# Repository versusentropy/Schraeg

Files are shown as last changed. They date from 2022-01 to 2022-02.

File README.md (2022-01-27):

# Schräg

Schräg is an 8HP multimode filter module for the eurorack format, based off the [Bastl Cinnamon](https://bastl-instruments.com/eurorack/modules/cinnamon).



## Smaller Warning and Disclaimer

As of 2021-03-01, at least one person has reported successfully building the current board revision. However, another builder reported a minor issue with the attenuverter circuits which prevents full-range voltage control over resonance (and limits voltage control over FM). This should be fixable only with component substitutions, we’re working on a fix. More information and updates [in the corresponding lines thread](https://llllllll.co/t/diy-module-release-schrag-bastl-cinnamon-rework/40590).

See the Changelog below for more updates and version-specific fixes.

## Quick links

* [Schematic](Schraeg/Schraeg.pdf)
* [Gerbers](Schraeg/output)
* [BOM](Schraeg/Schraeg%20BOM.csv)
* [Schräg on ModularGrid](https://www.modulargrid.net/e/other-unknown-schraeg)

## Features

Schräg is effectively a repackaged Bastl Cinnamon:

* Multimode filter with independent outputs (2-pole LP, 2-pole HP, 1-pole BP)
* V/oct input
* Self-resonates for use as a sine oscillator
* Input with an attenuator and 5x gain switch
* Two character switches for altering the resonance tracking
* All-SMD construction in a DIY-friendly format, with 0603 handsoldering footprints, all components on the back of the circuit board
* Built mostly using standard and easily-available components

with a few modifications:

* larger 8HP form factor, allowing for a big juicy cutoff knob and larger character and gain switches
* Voltage control over resonance, through an attenuverter
* FM input through an attenuverter, which works as a pitch fine-tune control with nothing patched
* A bi-directional power connector, with polyfuses
* An Interactive BOM (`Schraeg/Output/Interactive BOM.html` once you’ve cloned the repo locally) to aid in part placement
* Schematics and PCB laid out using KiCAD

The additional functionality is achieved with a minimum of extra components, thanks to the two unused VCA cells in the original design.

## License

The schematic, board layout and graphics are released under a cc-by-sa license. [Bastl Instruments](https://bastl-instruments.com/) generously gave their permission for me to release my rework of their module. They’re a cool company. Go check out their work!

## Development

In 2019 I was looking through the [Bastl Cinnamon schematic](https://github.com/bastl-instruments/bastlSchematics/blob/master/CINNAMON_V1.2.pdf) and realised that it only uses two of the four available V2164D VCA cells.

At the time I needed PCB layout practise (and a filter module for my DIY eurorack!), so I ended up prototyping and building an 8HP version of cinnamon for myself which uses the two spare cells to implement voltage control over resonance, as well as a few other little additions listed above.

I called it “Schräg” because of both the angled panel design, the weird sounds possible with Bastl’s cool distortion circuits, and the strange way KiCAD mangled the panel graphics.

A bit more than a year after building the first Schräg, I finally got around to fixing the various small issues with the first board revision, and asking Bastl if they were okay with me open-sourcing the project. They were, and here we are.

## Changelog

### v0.2.2

* Fixed attenuverter circuits (versusentroppy)
* Removed panel
* Added part numbers for JLCPCB
* Added placeholder for JLC's order number

### v0.2.1

* Fixed the LM4040 schematic symbols and PCB traces (#2)

### v0.2

* First version released to the public.
* These boards have an issue with the LM4040 orientation (see #2). Depending on the specific LM4040s, it may not cause any problems, but if building from scratch it’s best to install them correctly the first time. To fix it, solder the LM4040s at an angle so that pin 2 (NC) gets connected to pin 3 (5V Ref or GND, depending on the LM4040)

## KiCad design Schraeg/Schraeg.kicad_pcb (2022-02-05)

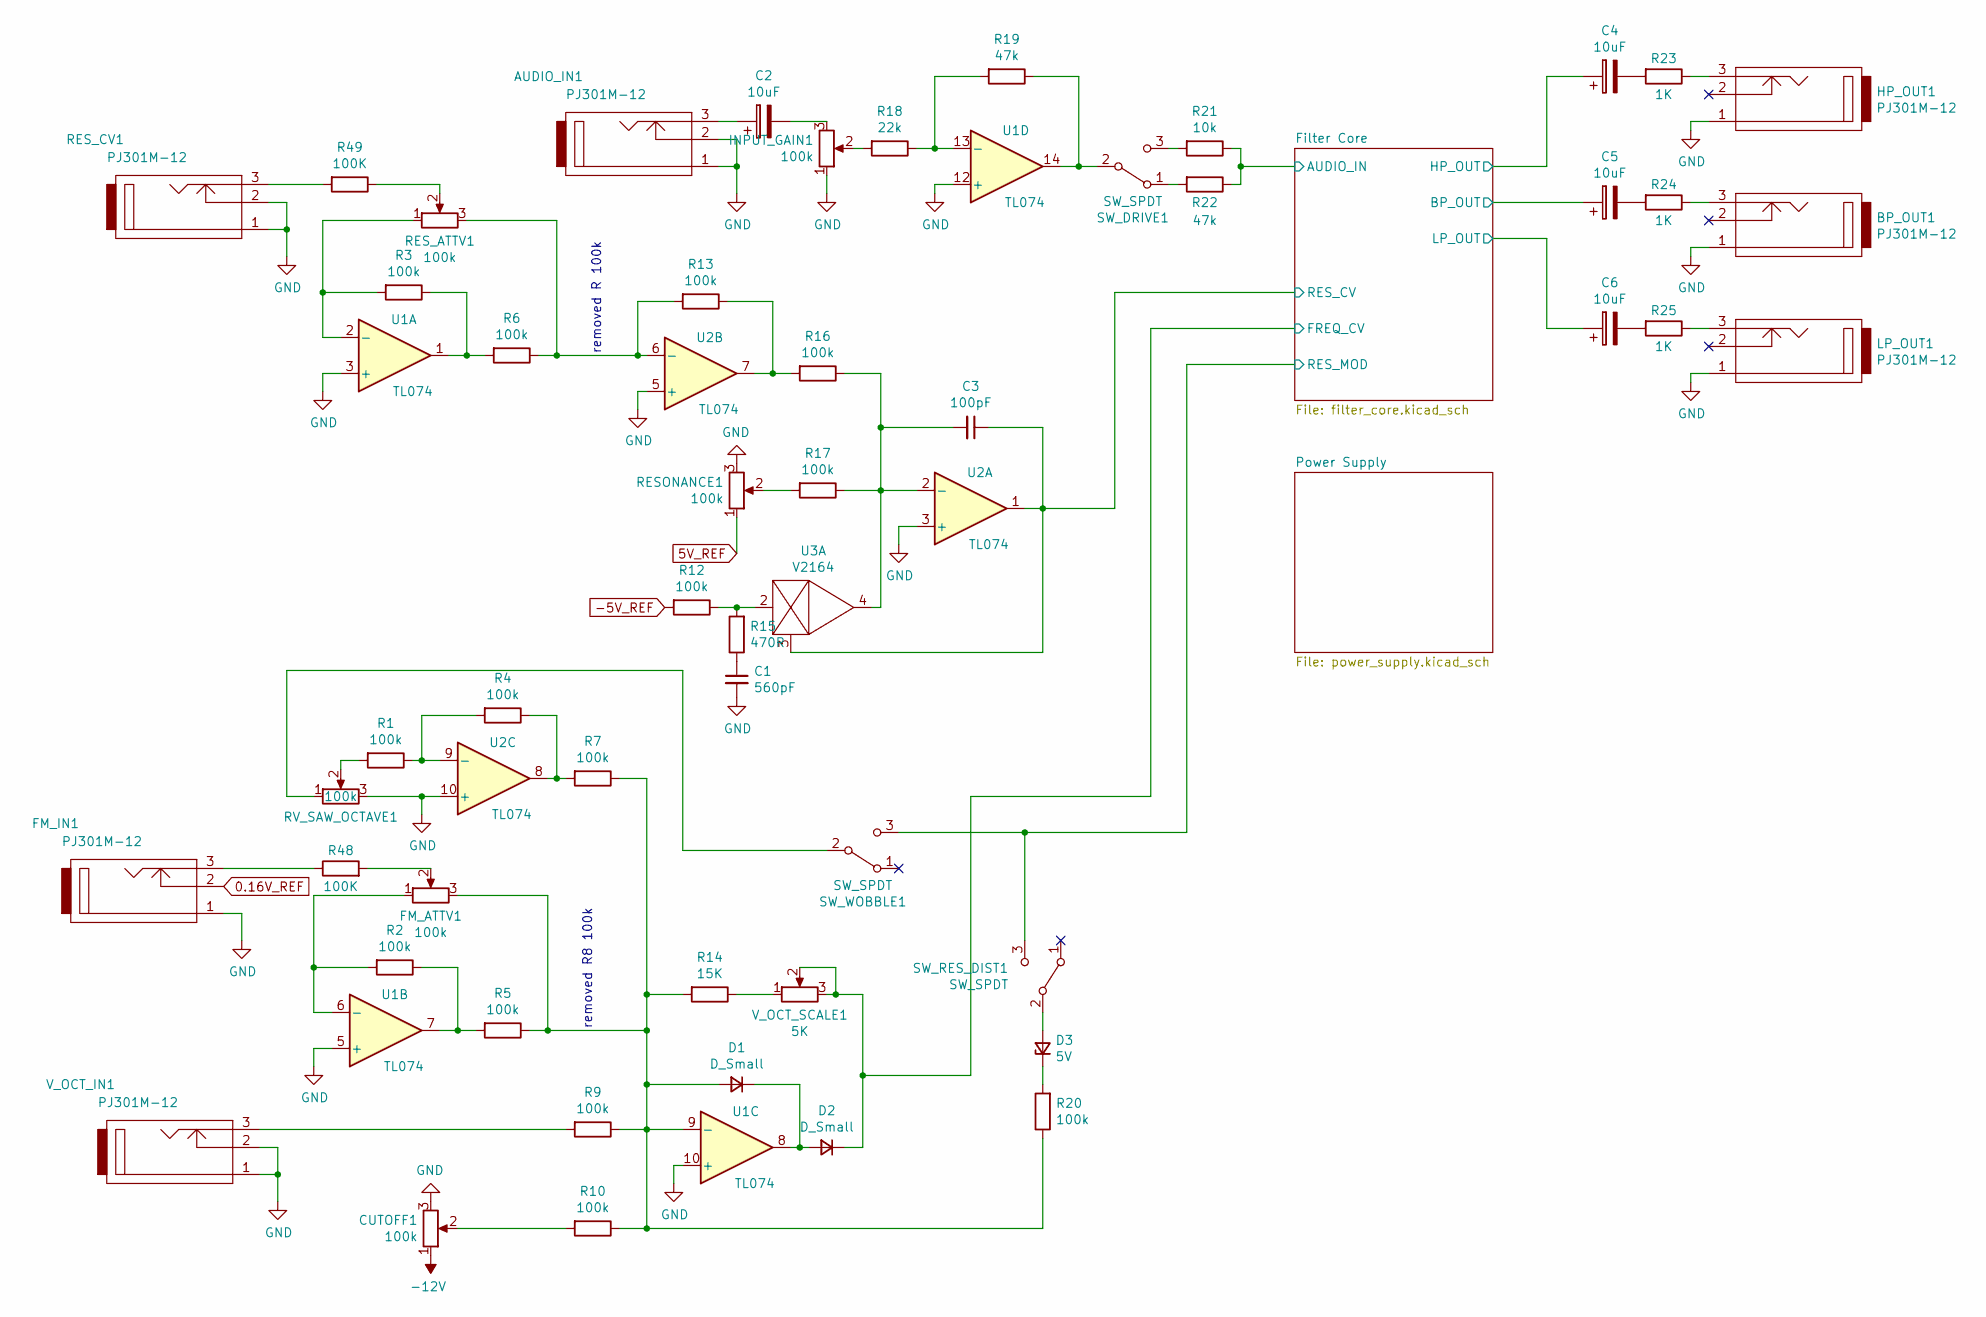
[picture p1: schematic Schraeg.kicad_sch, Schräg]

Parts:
AUDIO_IN1: PJ301M-12
BP_OUT1: PJ301M-12
C1: 560pF; C_0603_1608Metric_Pad1.05x0.95mm_HandSolder; LCSC C55393
C2, C4, C5, C6: 10uF; CP_Elec_5x4.5; Mouser 647-UCQ1V100MCL1GB
C3: 100pF; C_0603_1608Metric_Pad1.05x0.95mm_HandSolder; LCSC C14858
CUTOFF1: 100k; Alpha9mmPot
D1, D2: D_Small; D_SOD-123; LCSC C117948
D3: 5V; D_SOD-123; LCSC C173407
FM_ATTV1: 100k; Alpha9mmPot
FM_IN1: PJ301M-12
HP_OUT1: PJ301M-12
INPUT_GAIN1: 100k; Alpha9mmPot
LP_OUT1: PJ301M-12
R1, R2, R3, R4, R5, R6, R7, R9, R10, R12, R13, R16, R17, R20: 100k; R_0603_1608Metric_Pad1.05x0.95mm_HandSolder; LCSC C25803
R14: 15K; R_0603_1608Metric_Pad1.05x0.95mm_HandSolder; LCSC C22809
R15: 470R; R_0603_1608Metric_Pad1.05x0.95mm_HandSolder; LCSC C23179
R18: 22k; R_0603_1608Metric_Pad1.05x0.95mm_HandSolder; LCSC C31850
R19, R22: 47k; R_0603_1608Metric_Pad1.05x0.95mm_HandSolder; LCSC C25819
R21: 10k; R_0603_1608Metric_Pad1.05x0.95mm_HandSolder; LCSC C25804
R23, R24, R25: 1K; R_0603_1608Metric_Pad1.05x0.95mm_HandSolder; LCSC C21190
R48, R49: 100K; R_0603_1608Metric_Pad1.05x0.95mm_HandSolder; LCSC C25803
RESONANCE1: 100k; Alpha9mmPot
RES_ATTV1: 100k; Alpha9mmPot
RES_CV1: PJ301M-12
RV_SAW_OCTAVE1: 100k; Potentiometer_Bourns_3296W_Vertical
SW_DRIVE1: SW_SPDT; PinHeader_1x03_P2.54mm_Vertical
SW_RES_DIST1: SW_SPDT; PinHeader_1x03_P2.54mm_Vertical
SW_WOBBLE1: SW_SPDT; PinHeader_1x03_P2.54mm_Vertical
U1, U2: TL074; SOIC-14_3.9x8.7mm_P1.27mm; LCSC C12594
U3: V2164; SOIC-16_3.9x9.9mm_P1.27mm
V_OCT_IN1: PJ301M-12
V_OCT_SCALE1: 5K; Potentiometer_Bourns_3296W_Vertical

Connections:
0.16V_REF: FM_IN1.2; also elsewhere on the board
5V_REF: RESONANCE1.1; also elsewhere on the board
-5V_REF: R12.2; also elsewhere on the board
-12V: CUTOFF1.1; also elsewhere on the board
/Filter Core/AUDIO_IN: R21.1, R22.1; also elsewhere on the board
/Filter Core/BP_OUT: C5.1; also elsewhere on the board
/Filter Core/FREQ_CV: D2.1 (K), V_OCT_SCALE1.2, V_OCT_SCALE1.3; also elsewhere on the board
/Filter Core/HP_OUT: C4.1; also elsewhere on the board
/Filter Core/LP_OUT: C6.1; also elsewhere on the board
/Filter Core/RES_CV: C3.1, U2.1, U3.3; also elsewhere on the board
/Filter Core/RES_MOD: SW_RES_DIST1.3 (C), SW_WOBBLE1.3 (C); also elsewhere on the board
GND: AUDIO_IN1.1, AUDIO_IN1.2, BP_OUT1.1, C1.2, CUTOFF1.3, FM_IN1.1, HP_OUT1.1, INPUT_GAIN1.1, LP_OUT1.1, RESONANCE1.3, RES_CV1.1, RES_CV1.2, RV_SAW_OCTAVE1.3, U1.3 (+), U1.5 (+), U1.10 (+), U1.12 (+), U2.3 (+), U2.5 (+), U2.10 (+), V_OCT_IN1.1, V_OCT_IN1.2; also elsewhere on the board
unnamed: AUDIO_IN1.3, C2.1
unnamed: BP_OUT1.3, R24.1
unnamed: C1.1, R15.1
unnamed: C2.2, INPUT_GAIN1.3
unnamed: C3.2, R16.1, R17.1, U2.2 (-), U3.4
unnamed: C4.2, R23.2
unnamed: C5.2, R24.2
unnamed: C6.2, R25.2
unnamed: CUTOFF1.2, R10.2
unnamed: D1.1 (K), D2.2 (A), U1.8
unnamed: D1.2 (A), FM_ATTV1.3, R5.1, R7.1, R9.1, R10.1, R14.2, R20.1, U1.9 (-)
unnamed: D3.1 (K), R20.2
unnamed: D3.2 (A), SW_RES_DIST1.2 (B)
unnamed: FM_ATTV1.1, R2.2, U1.6 (-)
unnamed: FM_ATTV1.2, R48.2
unnamed: FM_IN1.3, R48.1
unnamed: HP_OUT1.3, R23.1
unnamed: INPUT_GAIN1.2, R18.2
unnamed: LP_OUT1.3, R25.1
unnamed: R1.1, R4.2, U2.9 (-)
unnamed: R1.2, RV_SAW_OCTAVE1.2
unnamed: R2.1, R5.2, U1.7
unnamed: R3.1, R6.2, U1.1
unnamed: R3.2, RES_ATTV1.1, U1.2 (-)
unnamed: R4.1, R7.2, U2.8
unnamed: R9.2, V_OCT_IN1.3
unnamed: R12.1, R15.2, U3.2
unnamed: R13.1, R16.2, U2.7
unnamed: R6.1, R13.2, RES_ATTV1.3, U2.6 (-)
unnamed: R14.1, V_OCT_SCALE1.1
unnamed: R17.2, RESONANCE1.2
unnamed: R18.1, R19.2, U1.13 (-)
unnamed: R19.1, SW_DRIVE1.2 (B), U1.14
unnamed: R21.2, SW_DRIVE1.3 (C)
unnamed: R22.2, SW_DRIVE1.1 (A)
unnamed: R49.1, RES_ATTV1.2
unnamed: R49.2, RES_CV1.3
unnamed: RV_SAW_OCTAVE1.1, SW_WOBBLE1.2 (B)

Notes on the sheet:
removed R8 100k
removed R 100k

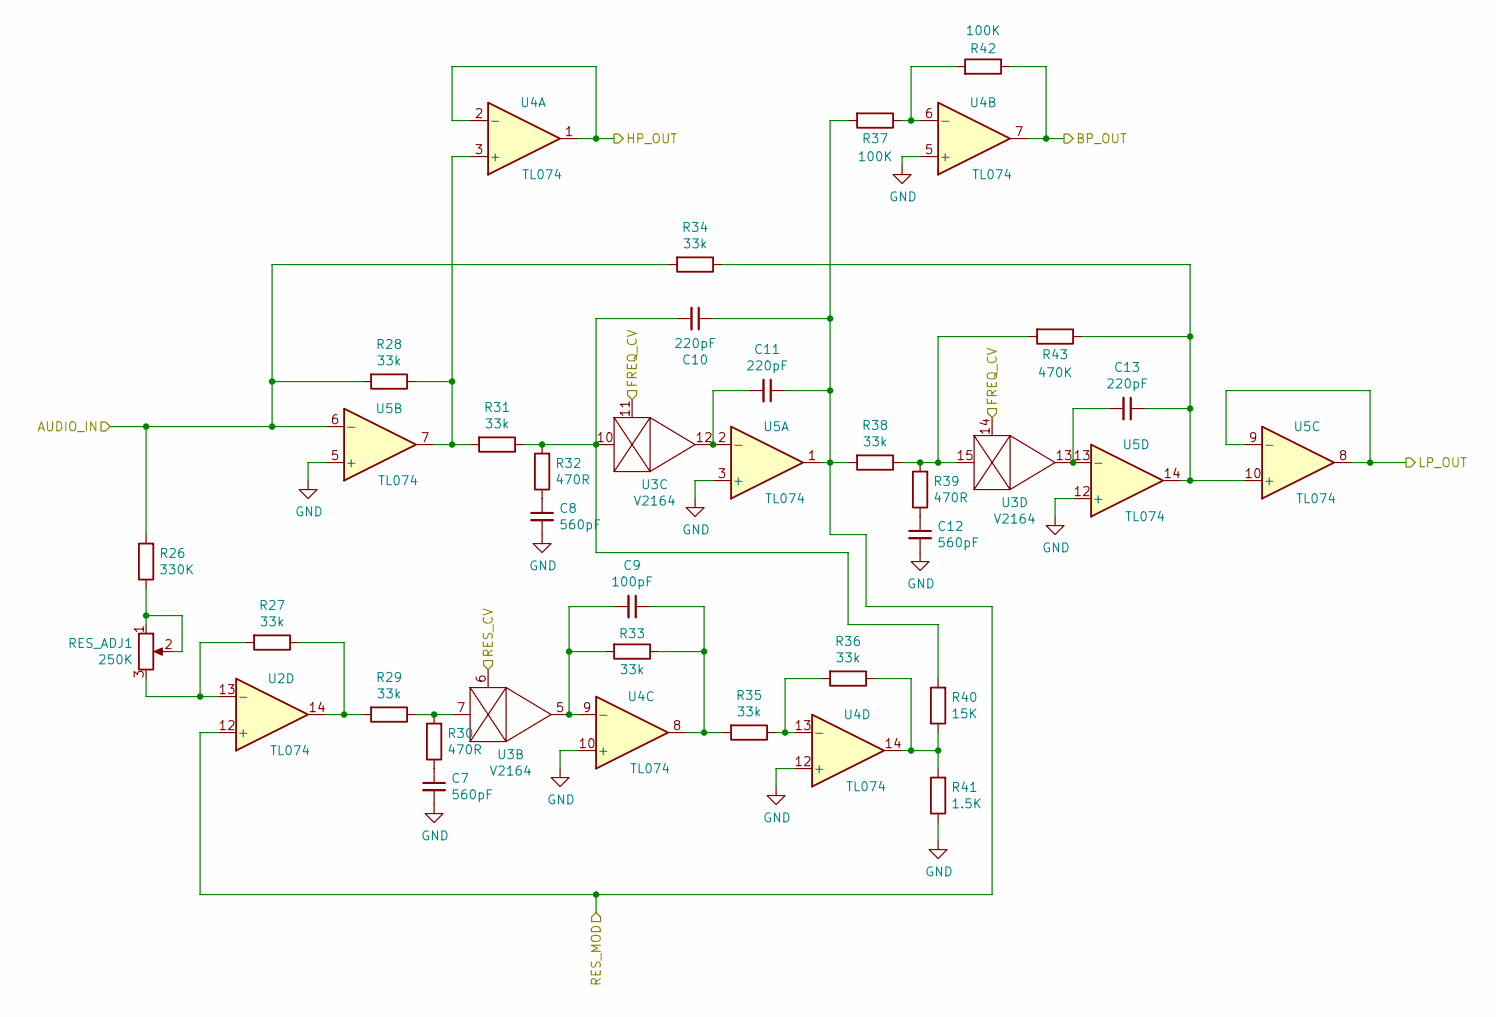
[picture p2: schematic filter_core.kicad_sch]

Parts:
C7, C8, C12: 560pF; C_0603_1608Metric_Pad1.05x0.95mm_HandSolder; LCSC C55393
C9: 100pF; C_0603_1608Metric_Pad1.05x0.95mm_HandSolder; LCSC C14858
C10, C11, C13: 220pF; C_0603_1608Metric_Pad1.05x0.95mm_HandSolder; LCSC C27675
R26: 330K; R_0603_1608Metric_Pad1.05x0.95mm_HandSolder; LCSC C23137
R27, R28, R29, R31, R33, R34, R35, R36, R38: 33k; R_0603_1608Metric_Pad1.05x0.95mm_HandSolder; LCSC C4216
R30, R32, R39: 470R; R_0603_1608Metric_Pad1.05x0.95mm_HandSolder; LCSC C23179
R37, R42: 100K; R_0603_1608Metric_Pad1.05x0.95mm_HandSolder; LCSC C25803
R40: 15K; R_0603_1608Metric_Pad1.05x0.95mm_HandSolder; LCSC C22809
R41: 1.5K; R_0603_1608Metric_Pad1.05x0.95mm_HandSolder; LCSC C22843
R43: 470K; R_0603_1608Metric_Pad1.05x0.95mm_HandSolder; LCSC C23178
RES_ADJ1: 250K; Potentiometer_Bourns_3296W_Vertical
U2, U4, U5: TL074; SOIC-14_3.9x8.7mm_P1.27mm; LCSC C12594
U3: V2164; SOIC-16_3.9x9.9mm_P1.27mm

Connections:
/Filter Core/AUDIO_IN: R26.2, R28.2, R34.2, U5.6 (-); also elsewhere on the board
/Filter Core/BP_OUT: R42.1, U4.7; also elsewhere on the board
/Filter Core/FREQ_CV: U3.11, U3.14; also elsewhere on the board
/Filter Core/HP_OUT: U4.1, U4.2 (-); also elsewhere on the board
/Filter Core/LP_OUT: U5.8, U5.9 (-); also elsewhere on the board
/Filter Core/RES_CV: U3.6; also elsewhere on the board
/Filter Core/RES_MOD: C10.1, C11.1, R37.2, R38.2, U2.12 (+), U5.1; also elsewhere on the board
GND: C7.2, C8.2, C12.2, R41.1, U4.5 (+), U4.10 (+), U4.12 (+), U5.3 (+), U5.5 (+), U5.12 (+); also elsewhere on the board
unnamed: C7.1, R30.1
unnamed: C8.1, R32.1
unnamed: C9.1, R33.1, R35.2, U4.8
unnamed: C9.2, R33.2, U3.5, U4.9 (-)
unnamed: C10.2, R31.1, R32.2, R40.2, U3.10
unnamed: C11.2, U3.12, U5.2 (-)
unnamed: C12.1, R39.1
unnamed: C13.1, R34.1, R43.1, U5.10 (+), U5.14
unnamed: C13.2, U3.13, U5.13 (-)
unnamed: R26.1, RES_ADJ1.1, RES_ADJ1.2
unnamed: R27.1, R29.2, U2.14
unnamed: R27.2, RES_ADJ1.3, U2.13 (-)
unnamed: R28.1, R31.2, U4.3 (+), U5.7
unnamed: R29.1, R30.2, U3.7
unnamed: R35.1, R36.2, U4.13 (-)
unnamed: R36.1, R40.1, R41.2, U4.14
unnamed: R37.1, R42.2, U4.6 (-)
unnamed: R38.1, R39.2, R43.2, U3.15

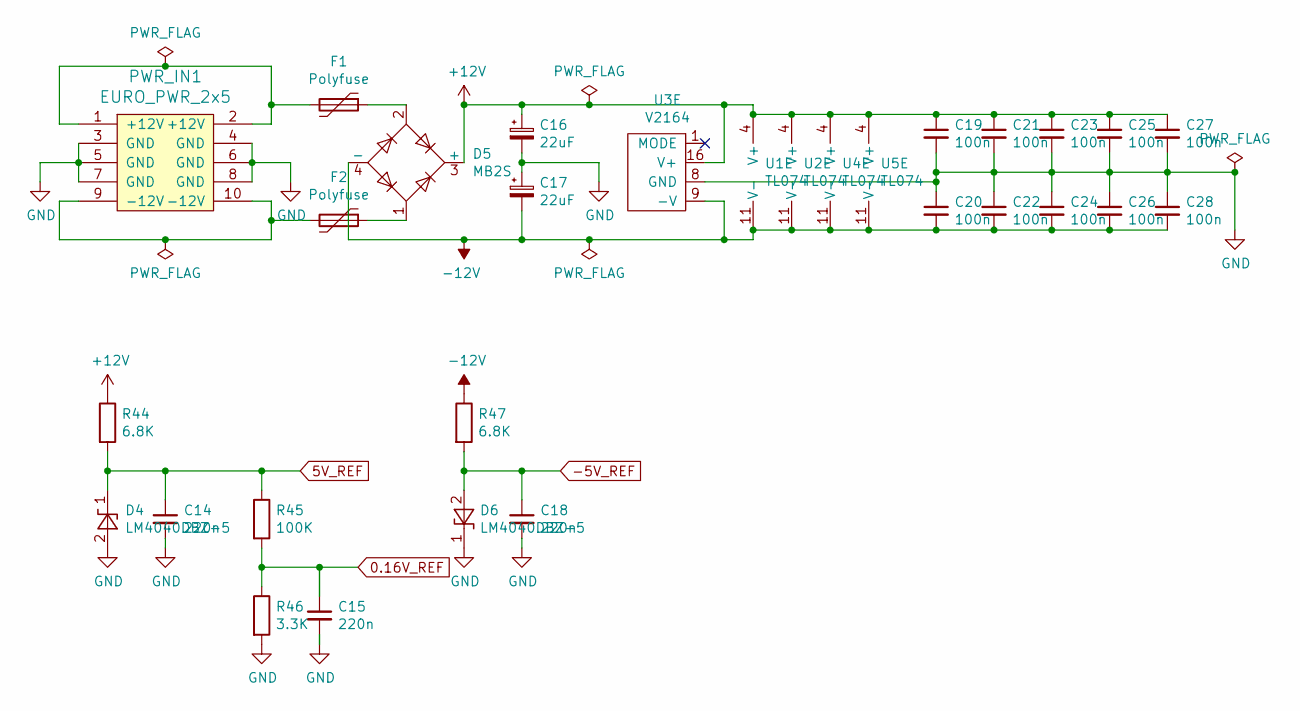
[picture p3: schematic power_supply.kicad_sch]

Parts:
C14, C15, C18: 220n; C_0603_1608Metric_Pad1.05x0.95mm_HandSolder; LCSC C21120
C16, C17: 22uF; CP_Elec_6.3x5.4; LCSC C72505
C19, C20, C21, C22, C23, C24, C25, C26, C27, C28: 100n; C_0603_1608Metric_Pad1.05x0.95mm_HandSolder; LCSC C14663
D4, D6: LM4040DBZ-5; SOT-23; LCSC C202168
D5: MB2S; TO-269AA; Mouser 625-MB2S-E3/80
F1, F2: Polyfuse; Fuse_1206_3216Metric_Pad1.42x1.75mm_HandSolder; LCSC C261946
PWR_IN1: EURO_PWR_2x5; PinHeader_2x05_P2.54mm_Vertical
R44, R47: 6.8K; R_0603_1608Metric_Pad1.05x0.95mm_HandSolder; LCSC C23212
R45: 100K; R_0603_1608Metric_Pad1.05x0.95mm_HandSolder; LCSC C25803
R46: 3.3K; R_0603_1608Metric_Pad1.05x0.95mm_HandSolder; LCSC C22978
U1, U2, U4, U5: TL074; SOIC-14_3.9x8.7mm_P1.27mm; LCSC C12594
U3: V2164; SOIC-16_3.9x9.9mm_P1.27mm

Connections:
0.16V_REF: C15.1, R45.2, R46.1; also elsewhere on the board
5V_REF: C14.1, D4.1 (K), R44.2, R45.1; also elsewhere on the board
+12V: C16.1, C19.1, C21.1, C23.1, C25.1, C27.1, D5.3 (+), R44.1, U1.4 (V+), U2.4 (V+), U3.16 (V+), U4.4 (V+), U5.4 (V+)
-5V_REF: C18.1, D6.2 (A), R47.2; also elsewhere on the board
-12V: C17.2, C20.2, C22.2, C24.2, C26.2, C28.2, D5.4 (-), R47.1, U1.11 (V-), U2.11 (V-), U3.9 (-V), U4.11 (V-), U5.11 (V-); also elsewhere on the board
GND: C14.2, C15.2, C16.2, C17.1, C18.2, C19.2, C20.1, C21.2, C22.1, C23.2, C24.1, C25.2, C26.1, C27.2, C28.1, D4.2 (A), D6.1 (K), PWR_IN1.3 (GND), PWR_IN1.4 (GND), PWR_IN1.5 (GND), PWR_IN1.6 (GND), PWR_IN1.7 (GND), PWR_IN1.8 (GND), R46.2, U3.8 (GND); also elsewhere on the board
unnamed: D5.1, F2.1
unnamed: D5.2, F1.1
unnamed: F1.2, PWR_IN1.1 (+12V), PWR_IN1.2 (+12V)
unnamed: F2.2, PWR_IN1.9 (-12V), PWR_IN1.10 (-12V)

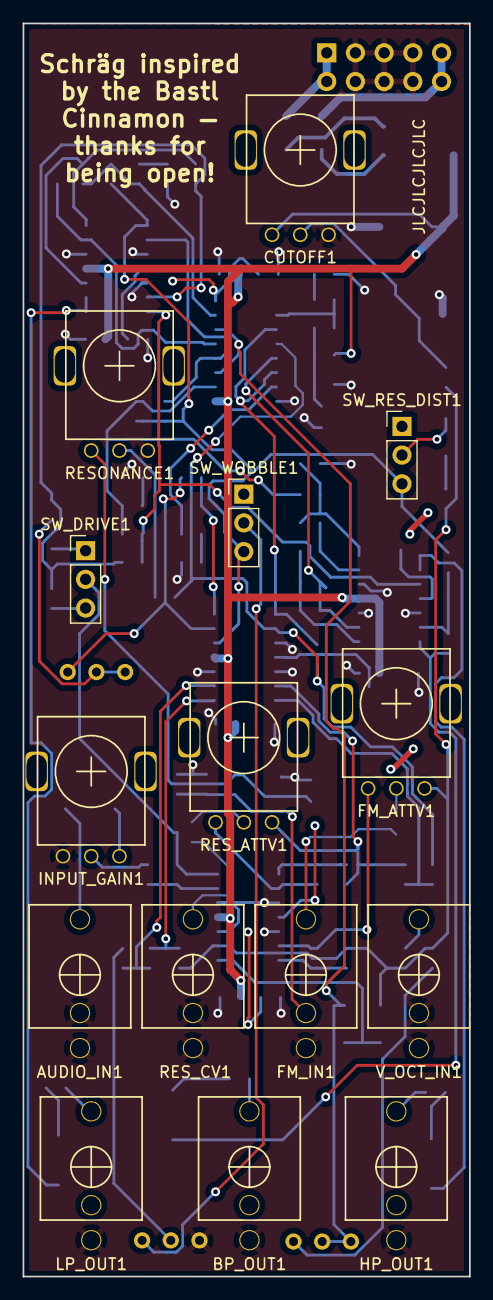
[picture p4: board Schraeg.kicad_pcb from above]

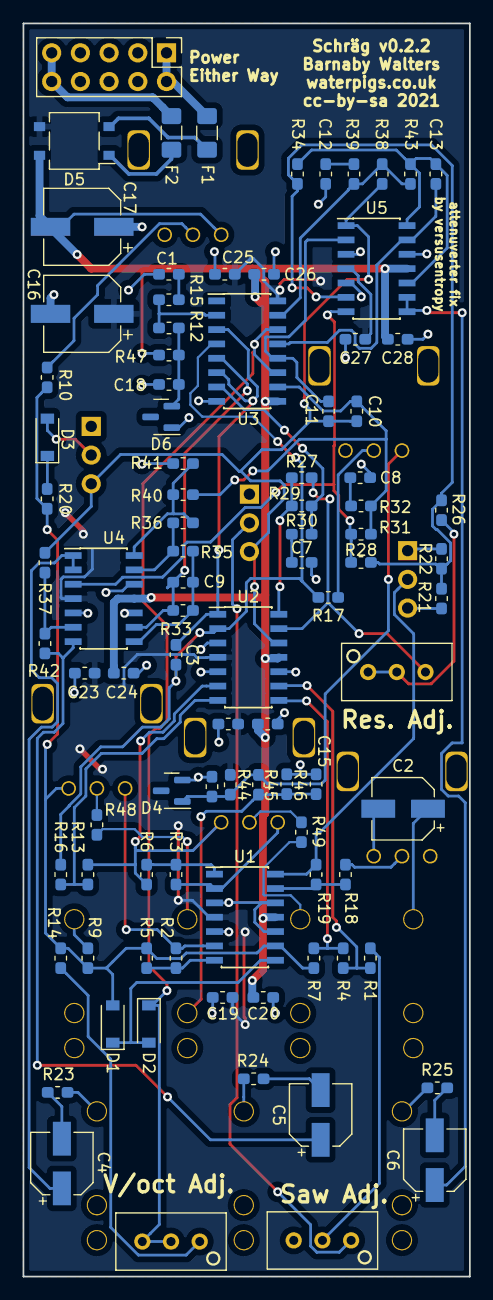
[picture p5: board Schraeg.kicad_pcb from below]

Board: 2 copper layers, 39.5 x 110.9 mm, 107 parts (92 on the bottom side), 73 nets.

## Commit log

2022-01-16 Add LCSC/Mouser BOM
    [Schraeg.kicad_sch, filter_core.kicad_sch, power_supply.kicad_sch]
2022-01-27 v0.2.2 BOM+POS+JLC placeholder
    [Schraeg-B.Cu.gbl, Schraeg-B.Mask.gbs, Schraeg-B.SilkS.gbo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]

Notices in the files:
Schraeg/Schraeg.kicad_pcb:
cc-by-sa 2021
